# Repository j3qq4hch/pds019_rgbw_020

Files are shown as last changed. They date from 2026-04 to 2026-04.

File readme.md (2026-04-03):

# PDS019_lit20

В этом репозитории содержатся исходники устройства PDS019_rgbw_020.

Конструктивно устройство представляет из себя две печатные платы, размещенные в корпусе для монтажа на DIN-рейку [GAINTA D4MG](https://www.gainta.com/en/d4mg.html)

<p align = center>
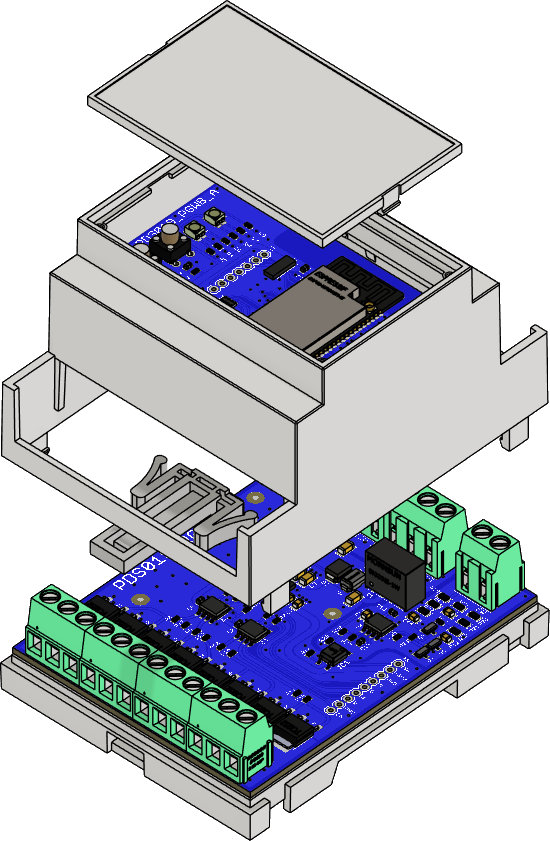
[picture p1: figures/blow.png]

</p>

# Внешний вид платы А (верхней платы)

<p align = center>
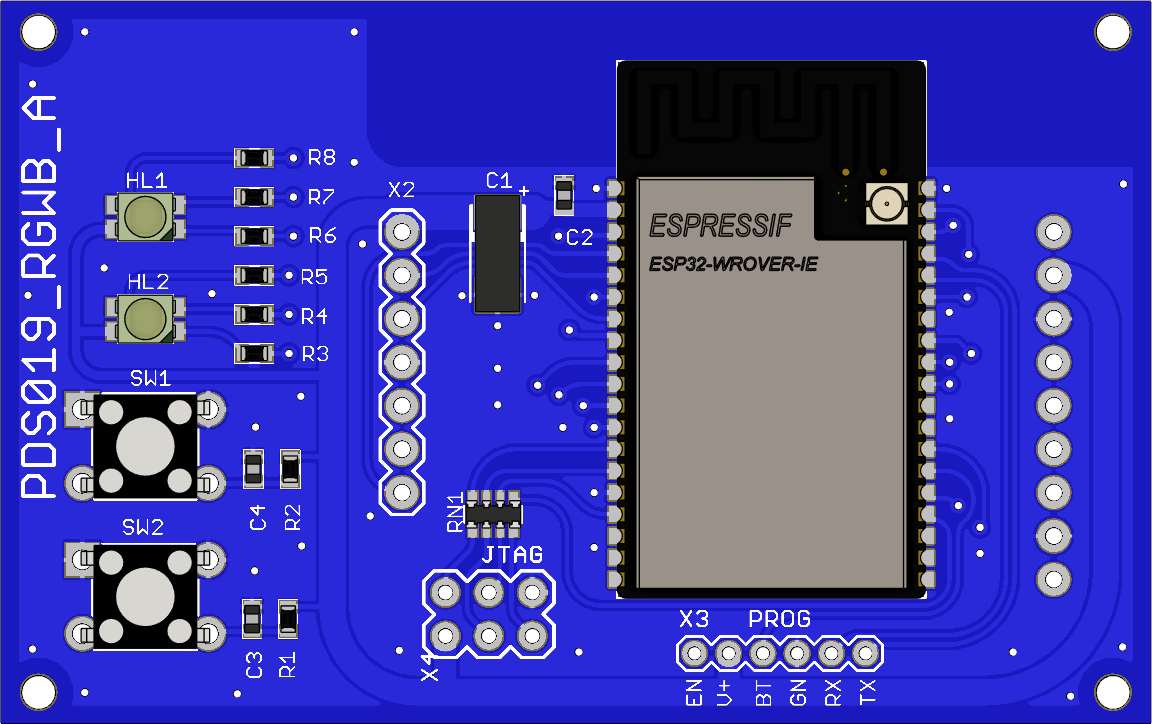
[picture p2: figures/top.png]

</p>

# Внешний вид платы B (нижней платы)

<p align = center>
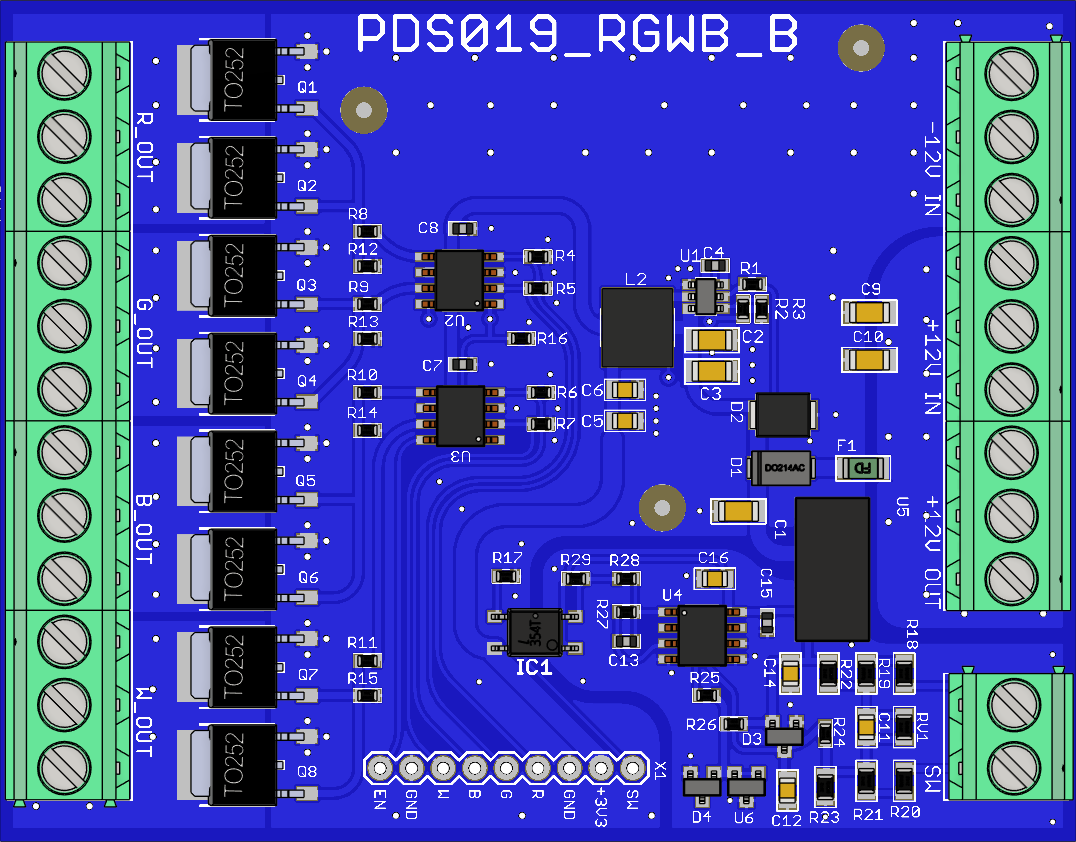
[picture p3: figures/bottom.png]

</p>

> [!IMPORTANT]
> Исходная документация (включая производственную документацию) хранится [здесь](https://github.com/j3qq4hch/pds019_rgbw_020/issues/1).

3d модель для онлайн просмотра доступна [по ссылке](https://a360.co/4bYYxEc)

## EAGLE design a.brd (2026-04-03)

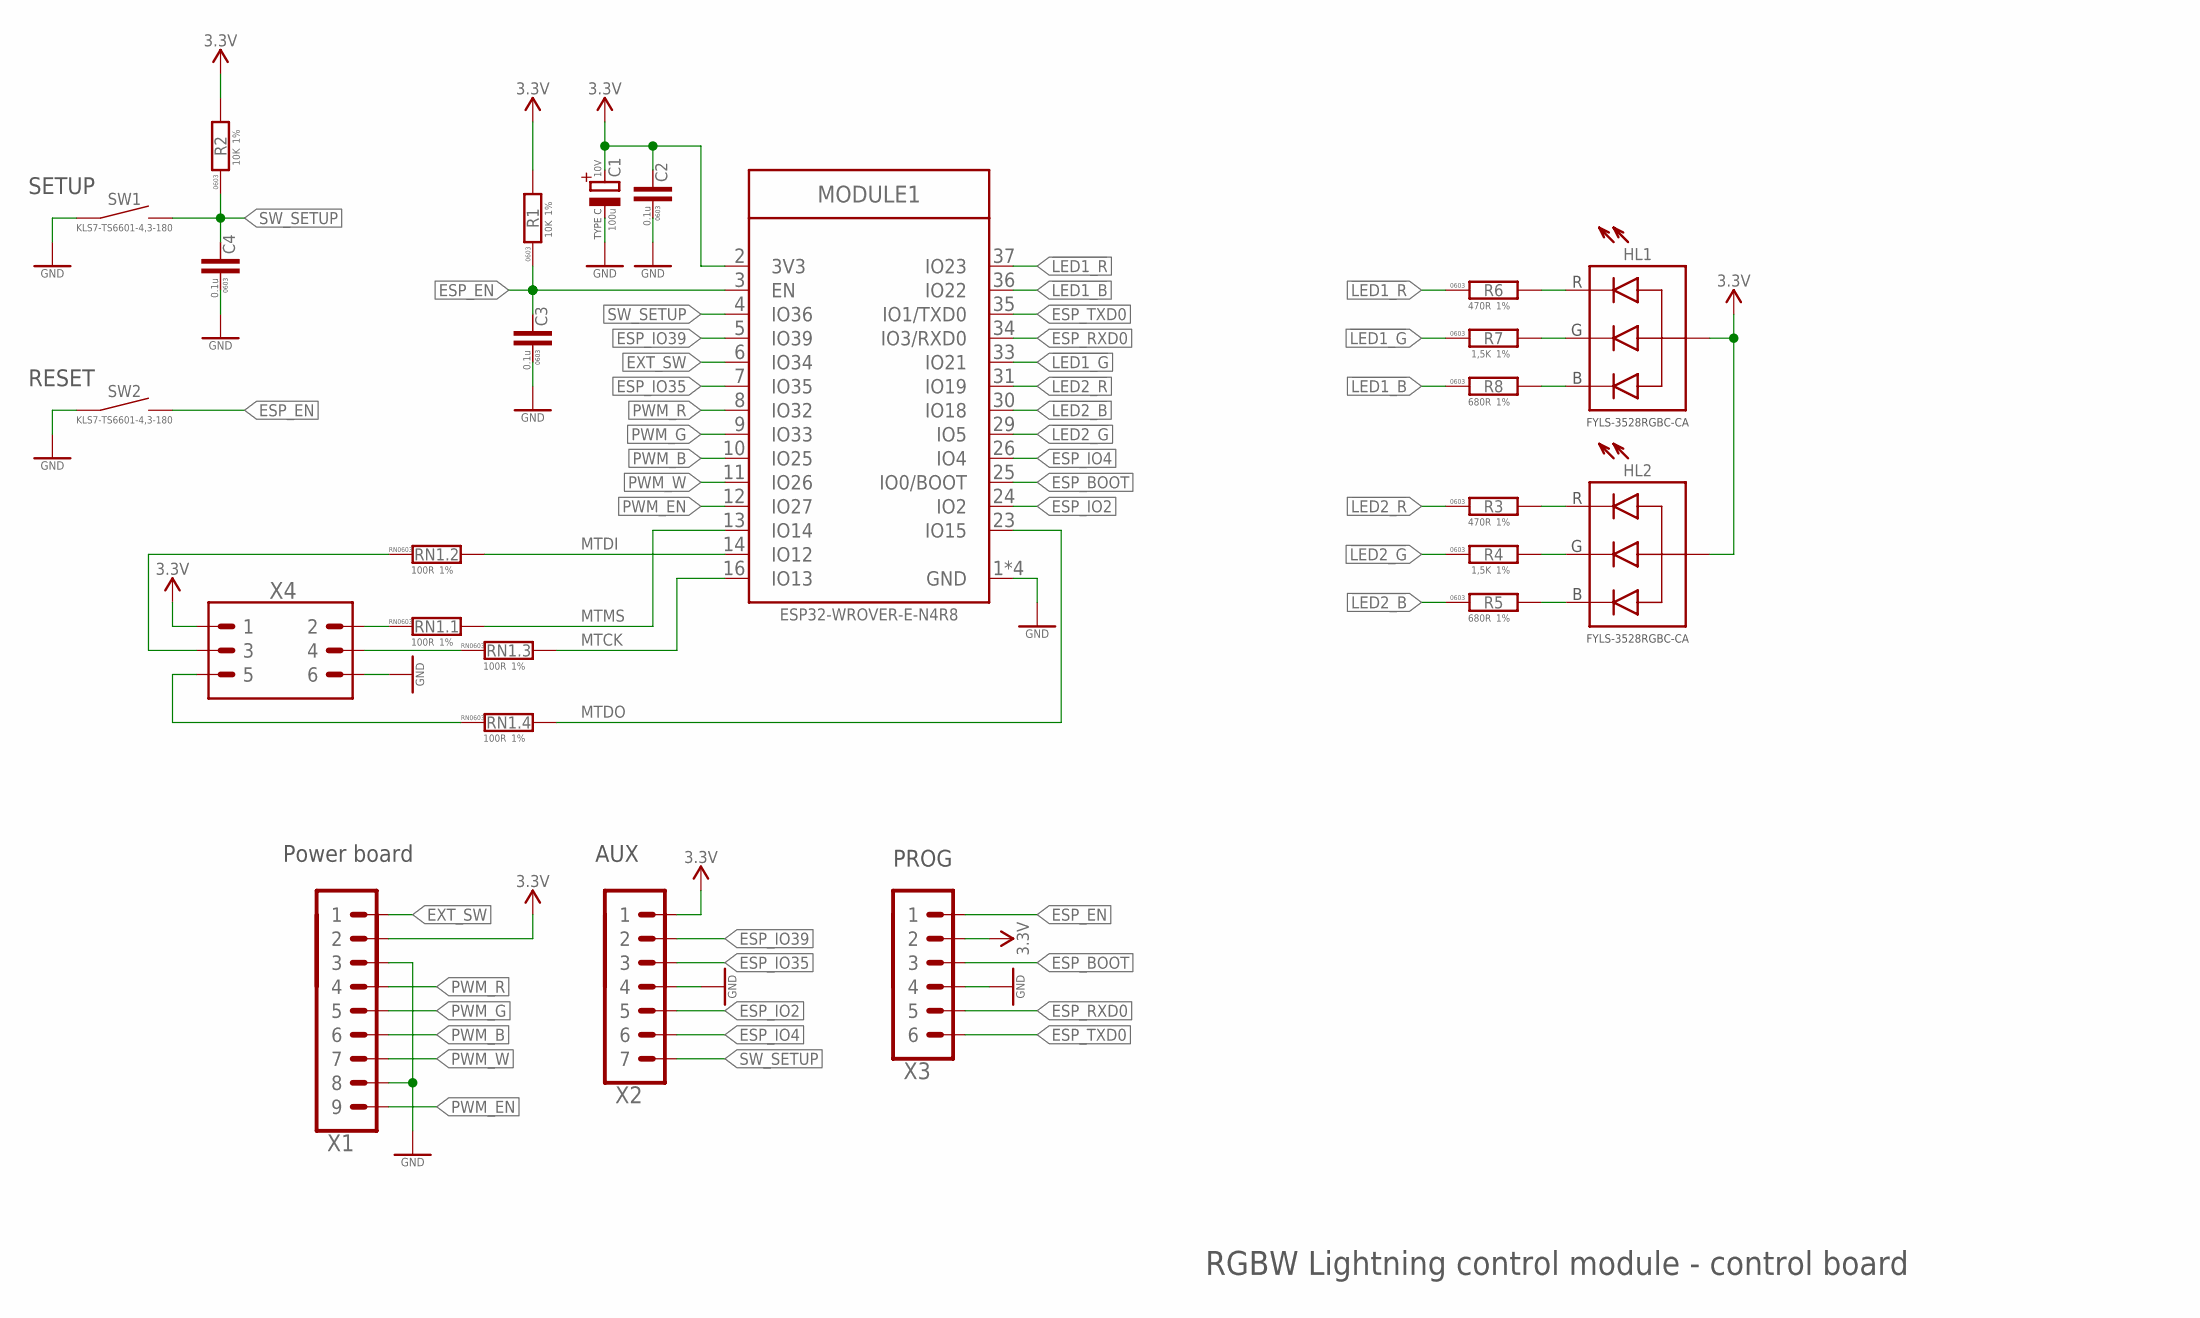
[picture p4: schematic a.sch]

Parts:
C1: 100u; CTANT_TYPE_C; VOLTAGE 10V
C2, C3, C4: 0.1u; C0603
HL1, HL2: LED_RGB-3528; LED3528
MODULE1: ESP32-WROVER-(I)E; ESP32-WROVER-E
R1, R2: 10K; R0603
R3, R6: 470R; R0603
R4, R7: 1,5K; R0603
R5, R8: 680R; R0603
RN1: 100R; R_4X0603
SW1, SW2: TS6601-9,5; SW4-6.0X6.0X5.0MM
X1: PINHEAD_1X09-2.54-TH-MALE; 1X09-PTH-2.54
X2: PINHEAD_1X07-2.54; 1X07-PTH-2.54
X3: PINHEAD_1X06-2-MALE; 1X06-PTH-2
X4: PINHEAD_2X03-PTH-2.54; 2X03-PTH-2.54

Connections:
!LED1_B: MODULE1.36 (IO22), R8.1
!LED1_G: MODULE1.33 (IO21), R7.1
!LED1_R: MODULE1.37 (IO23), R6.1
!LED2_B: MODULE1.30 (IO18), R5.1
!LED2_G: MODULE1.29 (IO5), R4.1
!LED2_R: MODULE1.31 (IO19), R3.1
ESP_BOOT: MODULE1.25 (IO0/BOOT), X3.3
ESP_EN: C3.2, MODULE1.3 (EN), R1.1, SW2.2, SW2.3 (2), X3.1
ESP_IO2: MODULE1.24 (IO2), X2.5
ESP_IO4: MODULE1.26 (IO4), X2.6
ESP_IO35: MODULE1.7 (IO35), X2.3
ESP_IO39: MODULE1.5 (IO39), X2.2
ESP_RXD0: MODULE1.34 (IO3/RXD0), X3.5
ESP_TXD0: MODULE1.35 (IO1/TXD0), X3.6
EXT_SW: MODULE1.6 (IO34), X1.1
GND: C1.-, C2.1, C3.1, C4.1, MODULE1.1 (GND), MODULE1.15 (GND), MODULE1.38 (GND), MODULE1.39 (GND), SW1.1, SW1.4 (1), SW2.1, SW2.4 (1), X1.3, X1.8, X2.4, X3.4, X4.6
MTCK: MODULE1.16 (IO13), RN1.6 (2)
MTDI: MODULE1.14 (IO12), RN1.7 (2)
MTDI_J: RN1.2 (1), X4.3
MTDO: MODULE1.23 (IO15), RN1.5 (2)
MTMS: MODULE1.13 (IO14), RN1.8 (2)
unnamed: HL2.1 (R), R3.2
unnamed: HL1.4 (G), R7.2
unnamed: HL1.1 (R), R6.2
unnamed: HL1.3 (B), R8.2
unnamed: HL2.4 (G), R4.2
unnamed: RN1.1, X4.2
unnamed: RN1.3 (1), X4.4
unnamed: RN1.4 (1), X4.5
unnamed: HL2.3 (B), R5.2
PWM_B: MODULE1.10 (IO25), X1.6
PWM_EN: MODULE1.12 (IO27), X1.9
PWM_G: MODULE1.9 (IO33), X1.5
PWM_R: MODULE1.8 (IO32), X1.4
PWM_W: MODULE1.11 (IO26), X1.7
SW_SETUP: C4.2, MODULE1.4 (IO36), R2.1, SW1.2, SW1.3 (2), X2.7
VDD_3V3: C1.+, C2.2, HL1.2 (A), HL2.2 (A), MODULE1.2 (3V3), R1.2, R2.2, X1.2, X2.1, X3.2, X4.1

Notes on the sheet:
RESET
SETUP
PROG
Power board
RGBW Lightning control module - control board
AUX

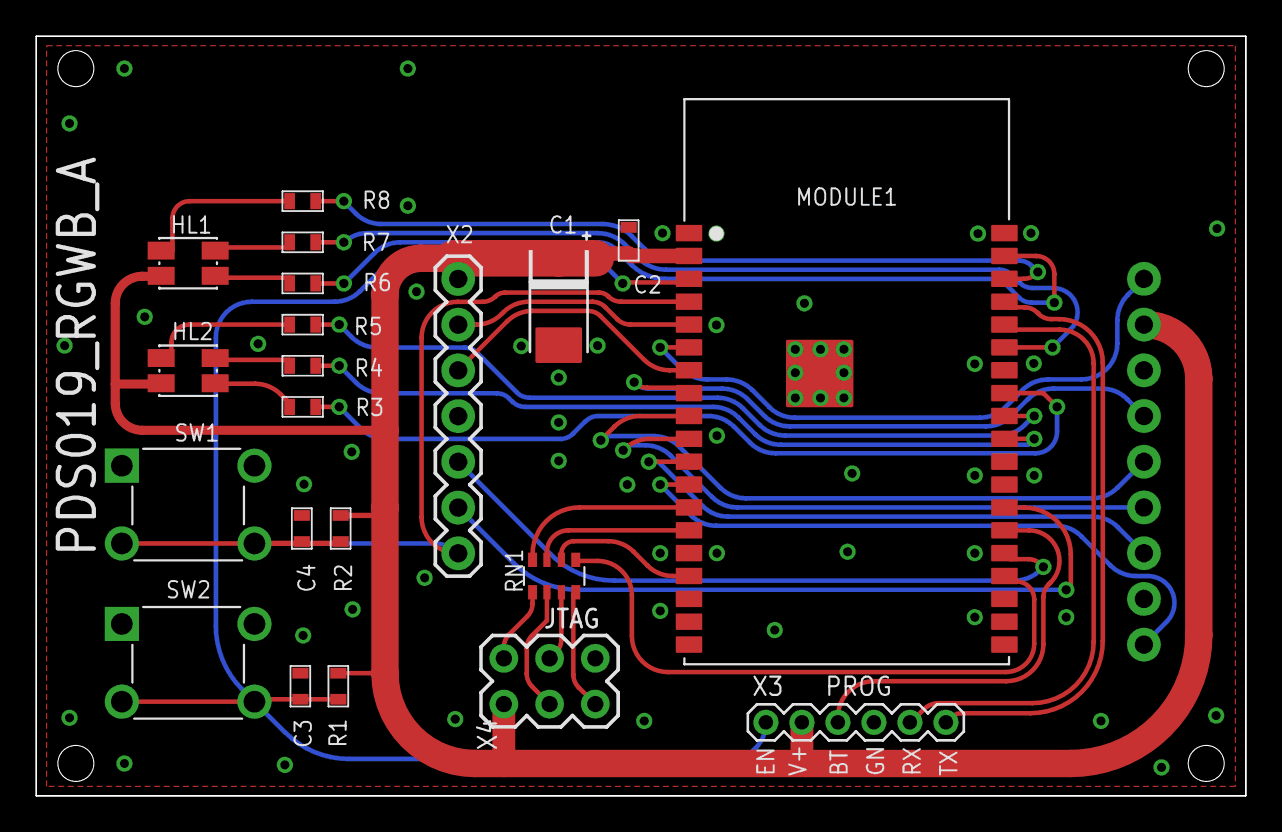
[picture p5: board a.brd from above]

Board: 2 copper layers, 67.2 x 42.2 mm, 23 parts (1 on the bottom side), 37 nets.

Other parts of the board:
PCB1: D4MG_PCB_UP

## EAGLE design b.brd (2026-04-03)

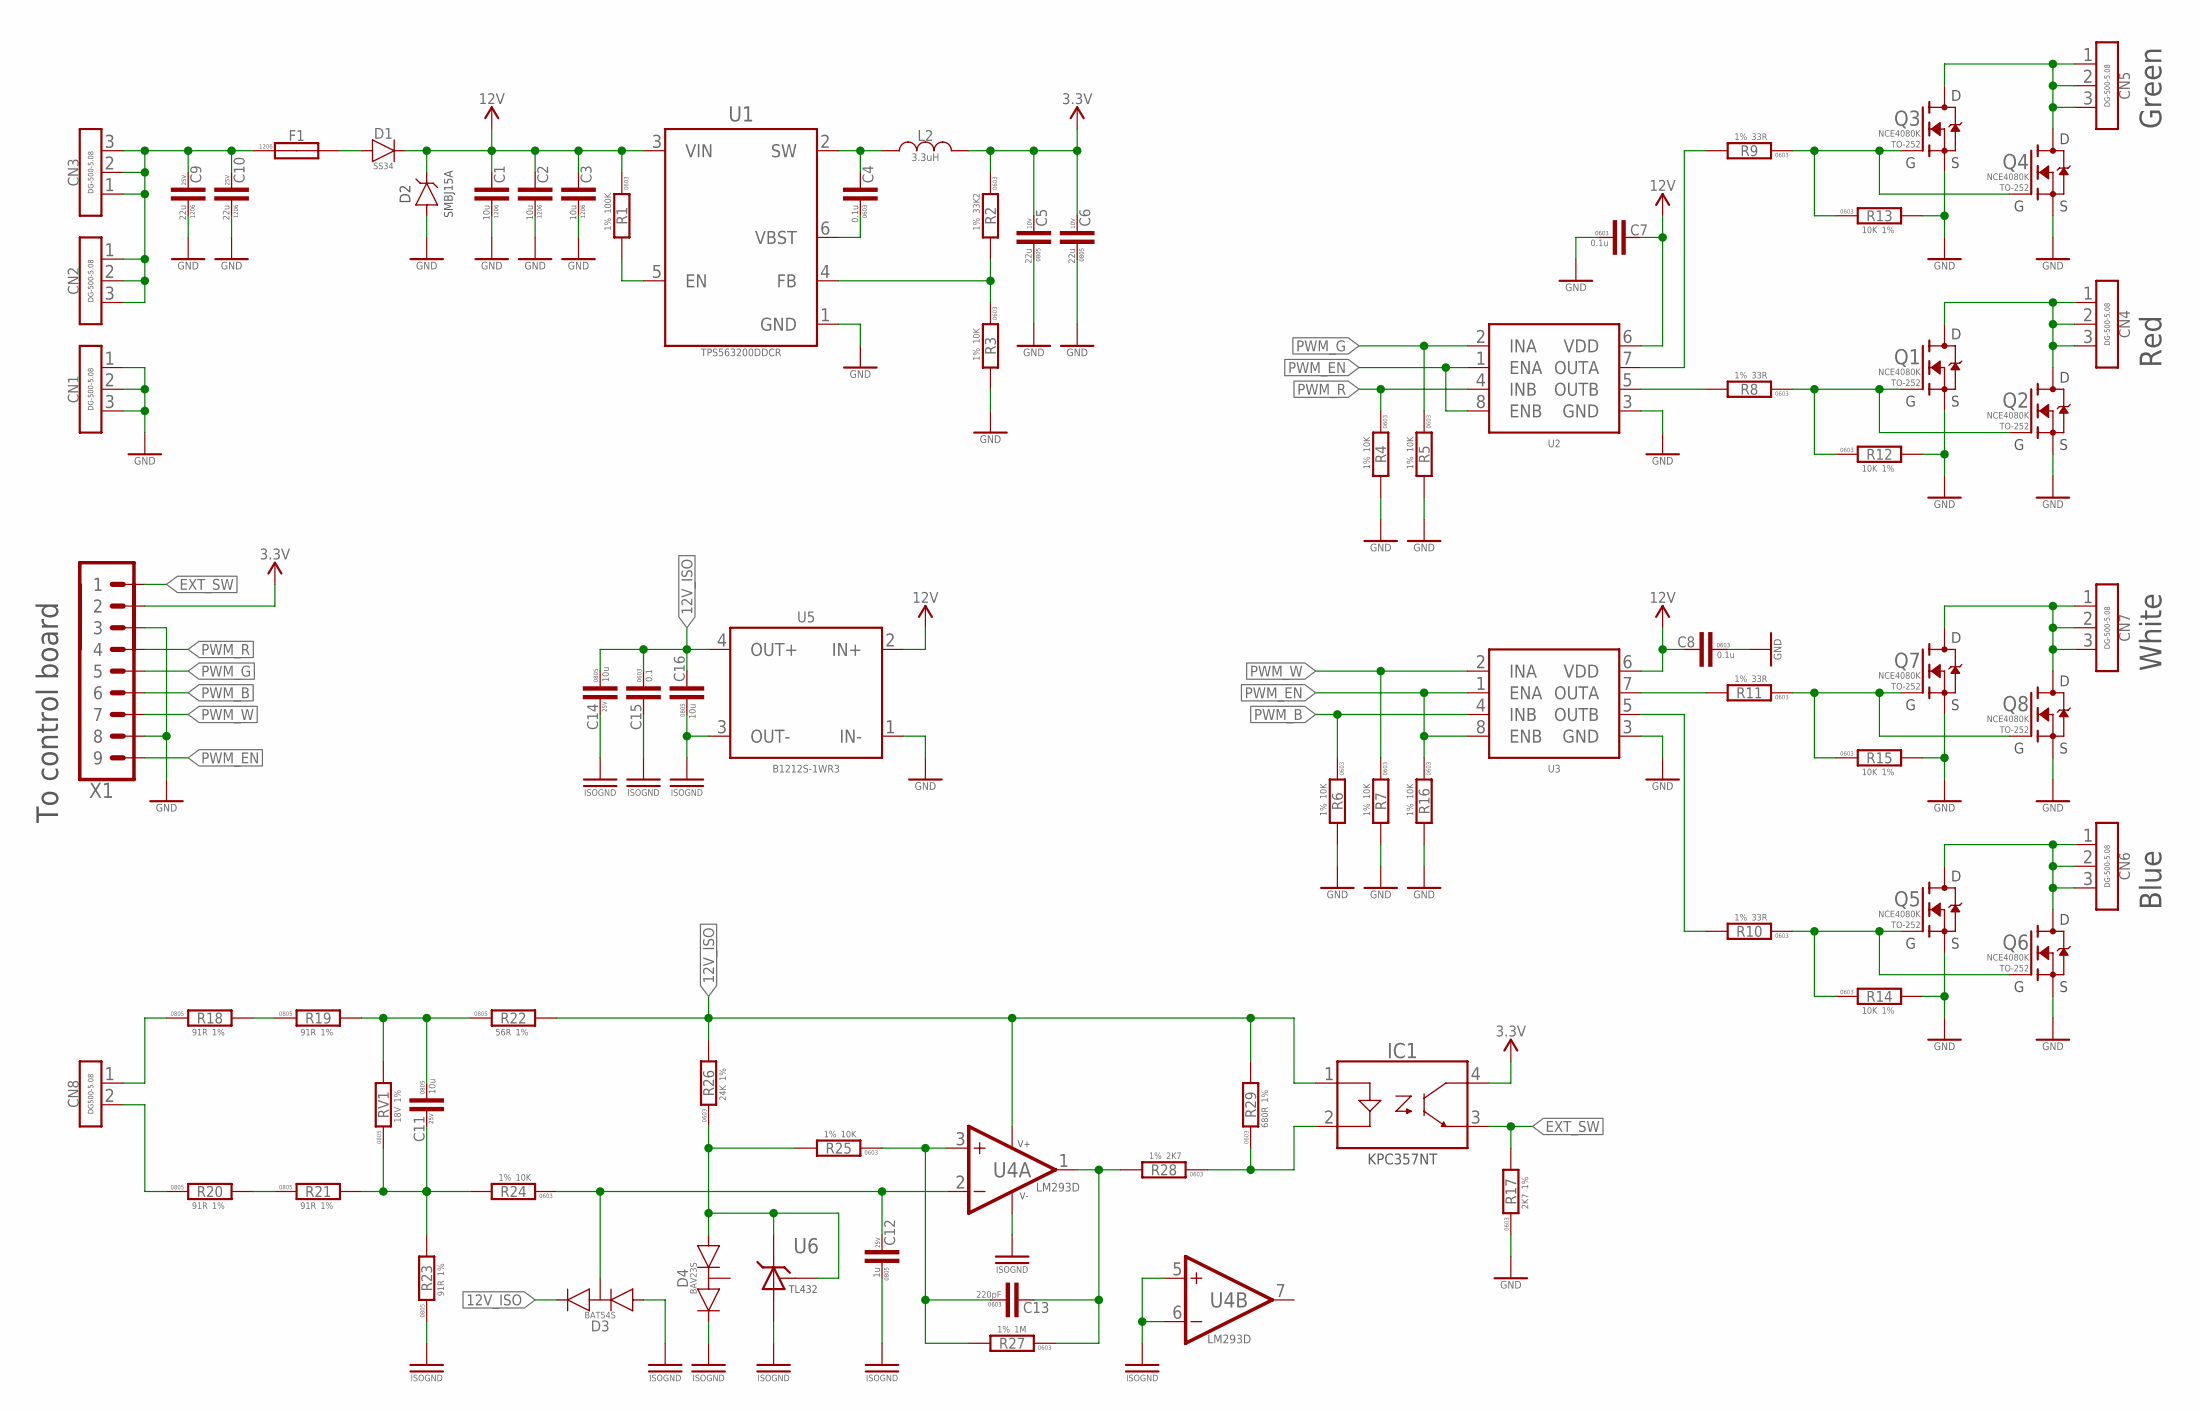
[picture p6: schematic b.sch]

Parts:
C1, C2, C3: 10u; C1206
C4, C7, C8: 0.1u; C0603
C5, C6: 22u; C0805; VOLTAGE 10V
C9, C10: 22u; C1206; VOLTAGE 25V
C11, C14: 10u; C0805; VOLTAGE 25V
C12: 1u; C0805; VOLTAGE 25V
C13: 220pF; C0603
C15: 0.1; C0603
C16: 10u; C0805
CN1, CN2, CN3, CN4, CN5, CN6, CN7: CON-3P-DG500-5.08; DG500-5.08-03P
CN8: DG508V-2P; DG500-5.08-02P
D1: SS24; DO-214AC(SMA)
D2: SMBJ15A-SMB; DO-214AA(SMB)
D3: BAT54S; SOT23
D4: BAV23S-SOT23; SOT23
F1: eFUSE-1206-500mA; F1206
IC1: KPC357NT-SOP-4; -SOP-4
L2: 3.3uH; SWPA6020
Q1, Q2, Q3, Q4, Q5, Q6, Q7, Q8: 100N04; D-PAK
R1: 100K; R0603
R2: 33K2; R0603
R3, R4, R5, R6, R7, R12, R13, R14, R15, R16, R24, R25: 10K; R0603
R8, R9, R10, R11: 33R; R0603
R17, R28: 2K7; R0603
R18, R19, R20, R21, R23: 91R; R0805
R22: 56R; R0805
R26: 24K; R0603
R27: 1M; R0603
R29: 680R; R0603
RV1: 18V; R0805
U1: TPS563200; SOT23-6
U2, U3: PN7762S; SOIC8
U4: LM293D; SOIC8
U5: B1212S-1WR3; SIP-4
U6: TL432; SOT23B-3
X1: PINHEAD_1X09-2.54-TH-MALE; 1X09-PTH-2.54

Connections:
12V_ISO: C14.1, C15.1, C16.2, D3.2 (C), IC1.1 (A), R22.2, R26.2, R29.2, U4.8 (V+), U5.4 (OUT+)
B_OUT: CN6.1, CN6.2, CN6.3, Q5.D, Q6.D
EXT_SW: IC1.3 (EMITTER), R17.2, X1.1
GND: C1.P$1 (1), C2.P$1 (1), C3.P$1 (1), C5.1, C6.1, C7.1, C8.1, C9.P$1 (1), C10.P$1 (1), CN1.1, CN1.2, CN1.3, D2.A, Q1.S, Q2.S, Q3.S, Q4.S, Q5.S, Q6.S, Q7.S, Q8.S, R3.2, R4.2, R5.2, R6.2, R7.2, R12.2, R13.2, R14.2, R15.2, R16.2, R17.1, U1.1 (GND), U2.3 (GND), U3.3 (GND), U5.1 (IN-), X1.3, X1.8
G_OUT: CN5.1, CN5.2, CN5.3, Q3.D, Q4.D
ISOGND: C12.1, C14.2, C15.2, C16.1, D3.1 (A), D4.2 (C), R23.1, U4.4 (V-), U4.5 (IN+), U4.6 (IN-), U5.3 (OUT-), U6.3 (A)
unnamed: Q1.G, Q2.G, R8.1, R12.1
unnamed: R1.2, U1.5 (EN)
unnamed: Q3.G, Q4.G, R9.1, R13.1
unnamed: D1.A, F1.P$2 (2)
unnamed: R11.2, U3.7 (OUTA)
unnamed: R10.2, U3.5 (OUTB)
unnamed: R8.2, U2.5 (OUTB)
unnamed: Q5.G, Q6.G, R10.1, R14.1
unnamed: Q7.G, Q8.G, R11.1, R15.1
unnamed: C4.1, U1.6 (VBST)
unnamed: R9.2, U2.7 (OUTA)
unnamed: C4.2, L2.1, U1.2 (SW)
unnamed: IC1.2 (C), R28.1, R29.1
unnamed: R2.2, R3.1, U1.4 (FB)
unnamed: C13.2, R27.1, R28.2, U4.1 (OUT)
unnamed: C12.2, D3.3 (COMMON), R24.1, U4.2 (IN-)
unnamed: C11.1, R19.2, R22.1, RV1.2
unnamed: R18.2, R19.1
unnamed: R20.2, R21.1
unnamed: C13.1, R25.1, R27.2, U4.3 (IN+)
unnamed: D4.1 (A), R25.2, R26.1, U6.1 (R), U6.2 (C)
unnamed: C11.2, R21.2, R23.2, R24.2, RV1.1
PWM_B: R6.1, U3.4 (INB), X1.6
PWM_EN: R16.1, U2.1 (ENA), U2.8 (ENB), U3.1 (ENA), U3.8 (ENB), X1.9
PWM_G: R5.1, U2.2 (INA), X1.5
PWM_R: R4.1, U2.4 (INB), X1.4
PWM_W: R7.1, U3.2 (INA), X1.7
R_OUT: CN4.1, CN4.2, CN4.3, Q1.D, Q2.D
SW_IN+: CN8.1, R18.1
SW_IN-: CN8.2, R20.1
V+: C9.P$2 (2), C10.P$2 (2), CN2.1, CN2.2, CN2.3, CN3.1, CN3.2, CN3.3, F1.P$1 (1)
VDD_3V3: C5.2, C6.2, IC1.4 (COLLECTOR), L2.2, R2.1, X1.2
VDD_12V: C1.P$2 (2), C2.P$2 (2), C3.P$2 (2), C7.2, C8.2, D1.C, D2.C, R1.1, U1.3 (VIN), U2.6 (VDD), U3.6 (VDD), U5.2 (IN+)
Y_OUT: CN7.1, CN7.2, CN7.3, Q7.D, Q8.D

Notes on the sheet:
To control board
Red
Green
Blue
White

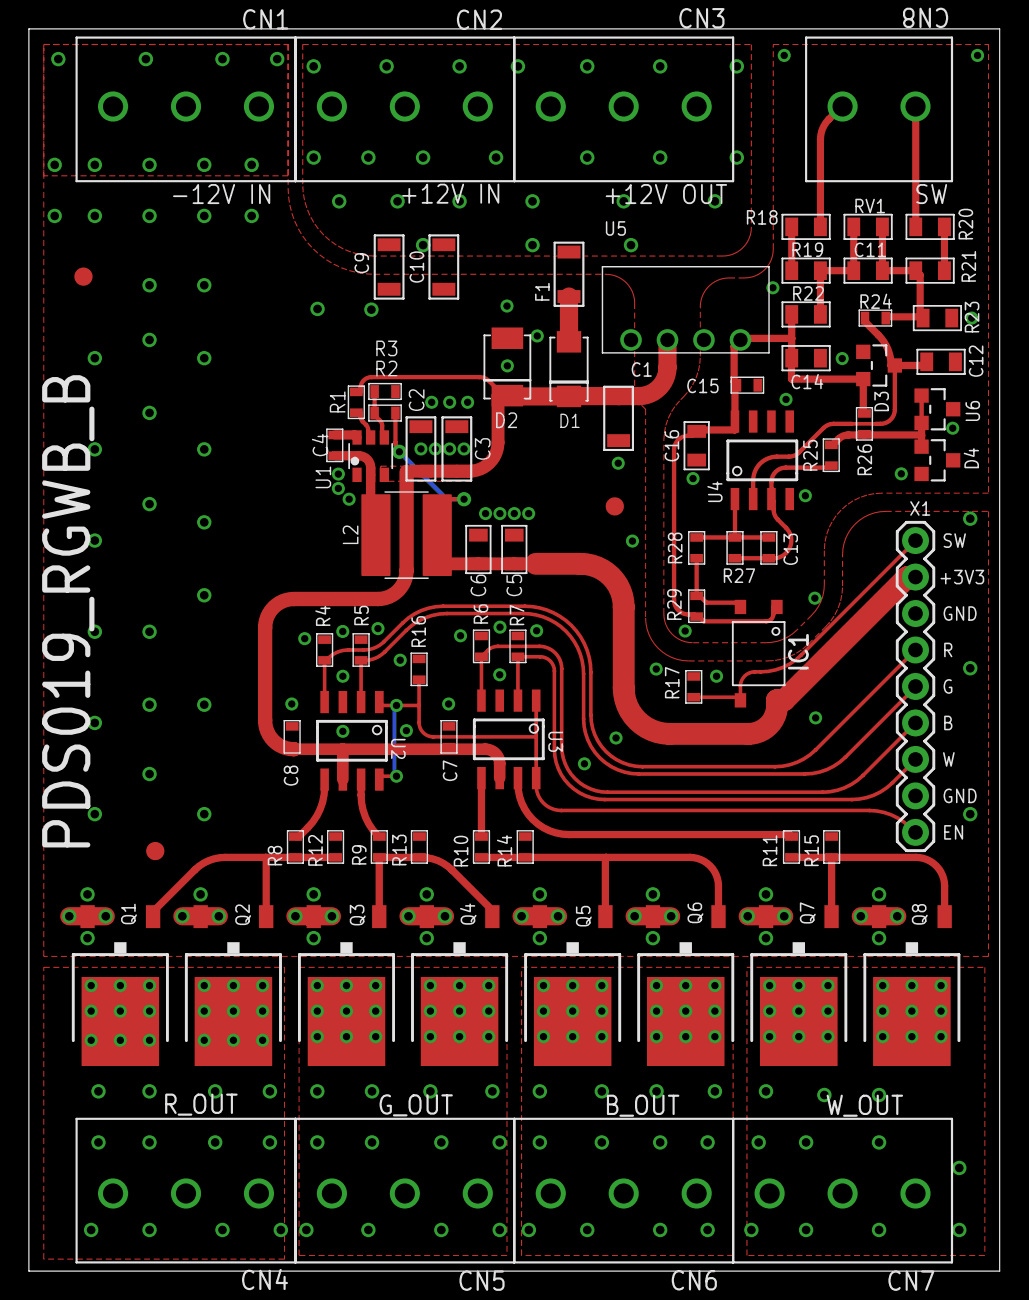
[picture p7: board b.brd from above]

Board: 2 copper layers, 67.6 x 86.5 mm, 80 parts (0 on the bottom side), 40 nets.

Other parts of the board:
PCB1: D4MG_PCB
REP1, REP2, REP3: REF_POINT_D1.27_D3.81

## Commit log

2026-04-03 a pcb
    [a.brd, a.sch]
2026-04-03 more import
    [a.brd, a.sch, b.brd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]
